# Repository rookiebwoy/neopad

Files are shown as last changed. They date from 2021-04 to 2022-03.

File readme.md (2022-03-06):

# Neopad

## Overview

Neopad is a little macropad with four switches and two rotary encoders, made by through hole components only. It's designed to use [QMK](https://qmk.fm/) firmware.
_Actually the number of switches is six, because even the encoder are allowed to click._

Neopad Neopad first proto

The Neopad in the photo above is the first prototype with ultra light case made from biscuits cardboard. In this repo you can find the final revision including:

+ fixed reset button pin routing
+ fixed positioning of mounting holes
+ added breakable PCB for EOTW case
+ new shiny artwork

Read the full development log on my website: [rookiebwoy.eu](https://www.rookiebwoy.eu/projects/neopad/neopad.html).

## In this repo

Here you can find my KiCad project files and the gerbers I used to manufacture the Neopad.
In order to open and modify them you will need to download and add the [keebio-components](https://github.com/keebio/keebio-components.git) symbols library to the project's path.

Neopad PCB front
PCB's frontside.

Neopad PCB back
PCB's backside.

## Description

+ The 2 LEDs rappresent the current layer in binary (max 4 layers rappresented but, accordingly with [QMK capabilities](https://beta.docs.qmk.fm/using-qmk/software-features/feature_layers), you can program up to 16 layers)
+ Total PCB dimensions are 99.22mm x 87.31mm
+ Macropad dimensions after build are 99.22mm x 42.86mm

## BOM

|Qty |Description |
|---:|:---|
|1x 	|Pro-Micro (or clone with ATmega32u4) |
|4x 	|Cherry MX compatible switches |
|2x 	|Encoders EC11 |
|6x |Diodes THT do-35 1N4148 |
|2x 	|Resistors 1/4W 220ohm 	 |
|2x 	|LEDs 3mm 	 |
|1x 	|Button switch 4 pin 6mm x 6mm	 |
|4x 	|M2 8mm standoff 	 |
|8x 	|M2 screws 	 |
|6x 	|Rubber feet 	 |
|4x 	|Keycaps 	 |
|2x 	|Knobs 	 |

## Firmware

You can find the QMK Firmware for Neopad on the official QMK repository at [this link](https://github.com/qmk/qmk_firmware/tree/master/keyboards/neopad).

## References

I decided to open source this project because I wanted to give back to the amazing mechanical keyboard comunity what was given to me. I owe special mention to the following links that I found extremely useful and that without them I could never achieve this:

+ the keyboard designer wiki [@ ai03.com](https://wiki.ai03.com/books/pcb-design/chapter/pcb-designer-guide) for KiCad's tutorial
+ Chokkan's [YouTube videos](https://www.youtube.com/watch?v=-HLV6mUxNnU) for setting up QMK's developing environment
+ imchipwood's [dumbpad macropad](https://github.com/imchipwood/dumbpad) for encoder's routing, LED's behavior, QMK and readme structure

## Donations

If you've found something useful, please consider helping me maintain [my website](https://www.rookiebwoy.eu/) online and further develop all my projects.

<p align="center">

</p>

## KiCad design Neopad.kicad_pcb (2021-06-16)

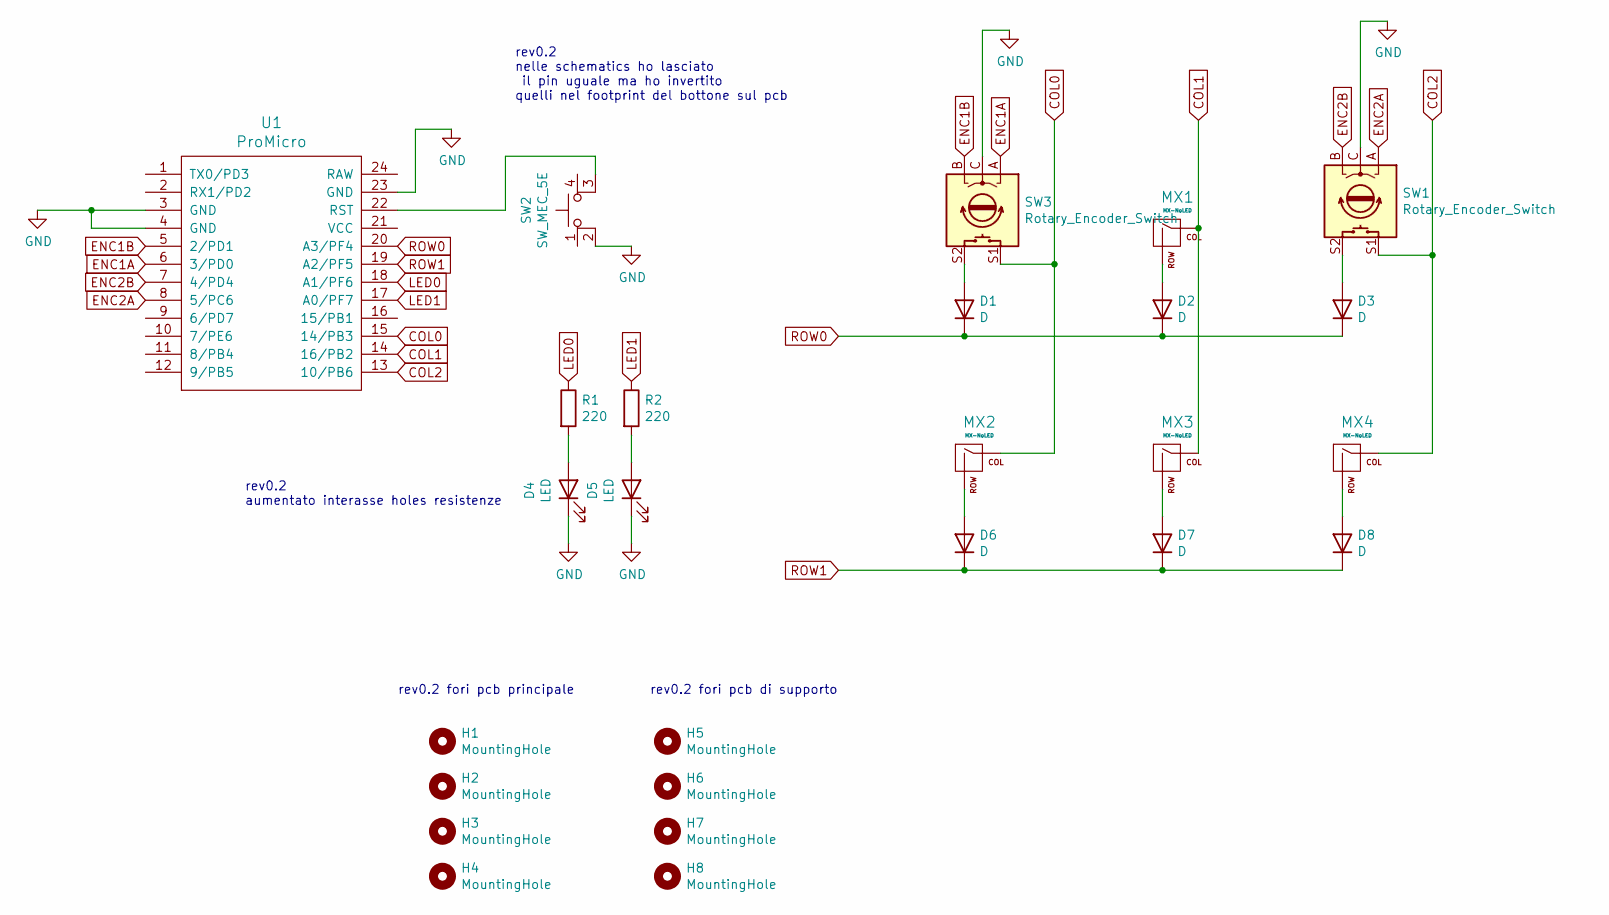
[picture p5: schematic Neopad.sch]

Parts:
D1, D2, D3, D6, D7, D8: D; Diode_DO-35_SOD27_P7.62mm
D4, D5: LED; LED_D3.0mm
H1, H2, H3, H4, H5, H6, H7, H8: MountingHole; MountingHole_D2.3mm
MX1, MX2, MX3, MX4: MX-NoLED; MXOnly-1U-NoLED
R1, R2: 220; R_Axial_P7.62mm
SW1, SW3: Rotary_Encoder_Switch; RotaryEncoder_Alps_EC11E-Switch
SW2: SW_MEC_5E; Button_SW_6mm
U1: ProMicro; ArduinoProMicro

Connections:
COL0: MX2.1 (COL), SW3.S1, U1.15 (14/PB3)
COL1: MX1.1 (COL), MX3.1 (COL), U1.14 (16/PB2)
COL2: MX4.1 (COL), SW1.S1, U1.13 (10/PB6)
ENC1A: SW3.A, U1.6 (3/PD0)
ENC1B: SW3.B, U1.5 (2/PD1)
ENC2A: SW1.A, U1.8 (5/PC6)
ENC2B: SW1.B, U1.7 (4/PD4)
GND: D4.1 (K), D5.1 (K), SW1.C, SW2.2, SW3.C, U1.3 (GND), U1.4 (GND), U1.23 (GND)
LED0: R1.1, U1.18 (A1/PF6)
LED1: R2.1, U1.17 (A0/PF7)
unnamed: D1.2 (A), SW3.S2
unnamed: D2.2 (A), MX1.2 (ROW)
unnamed: D3.2 (A), SW1.S2
unnamed: D4.2 (A), R1.2
unnamed: D5.2 (A), R2.2
unnamed: D6.2 (A), MX2.2 (ROW)
unnamed: D7.2 (A), MX3.2 (ROW)
unnamed: D8.2 (A), MX4.2 (ROW)
unnamed: SW2.3 (K), U1.22 (RST)
ROW0: D1.1 (K), D2.1 (K), D3.1 (K), U1.20 (A3/PF4)
ROW1: D6.1 (K), D7.1 (K), D8.1 (K), U1.19 (A2/PF5)

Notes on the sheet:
rev0.2 nelle schematics ho lasciato il pin uguale ma ho invertito quelli nel footprint del bottone sul pcb
rev0.2 aumentato interasse holes resistenze
rev0.2 fori pcb principale
rev0.2 fori pcb di supporto

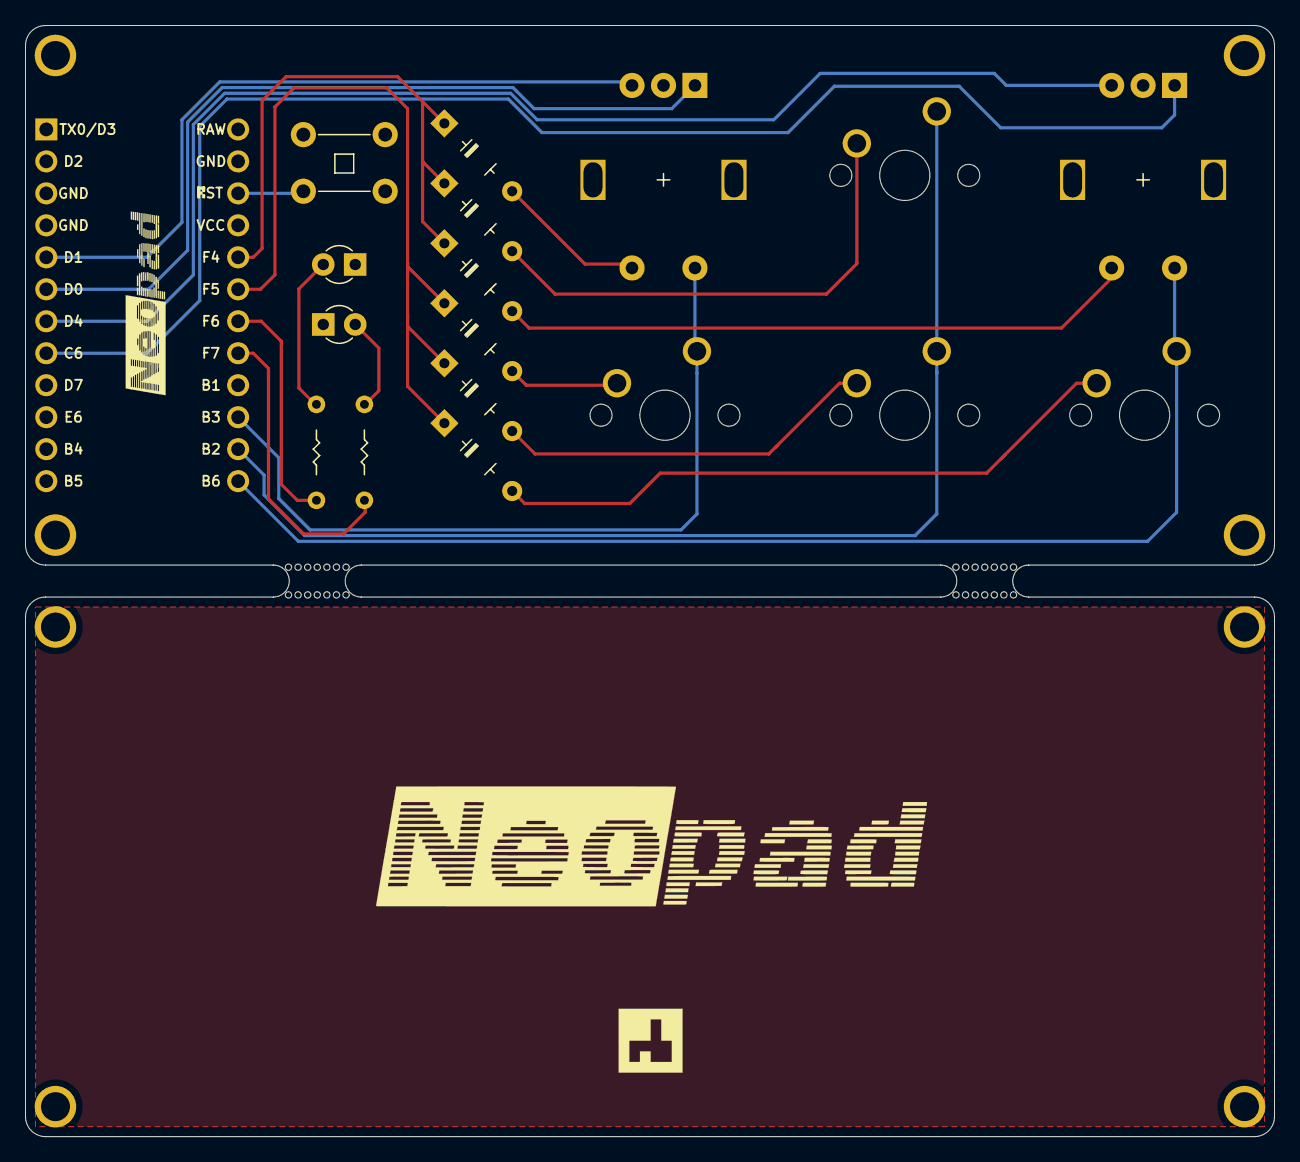
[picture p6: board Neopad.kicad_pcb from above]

Board: 2 copper layers, 99.2 x 88.3 mm, 28 parts (0 on the bottom side), 21 nets.

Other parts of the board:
mouse-bite-2.54mm-slot, mouse-bite-2.54mm-slot#2: VAL**; MouseBite-H2.54mm-W4.57mm

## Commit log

2021-04-18 aggiunti file progetto
    [Neopad-B_Cu.gbr, Neopad-B_Mask.gbr, Neopad-B_SilkS.gbr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]
2021-06-16 PCB revision for manufacturing improvement
    [Neopad-B_Cu.gbr, Neopad-B_Mask.gbr, Neopad-B_SilkS.gbr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]
